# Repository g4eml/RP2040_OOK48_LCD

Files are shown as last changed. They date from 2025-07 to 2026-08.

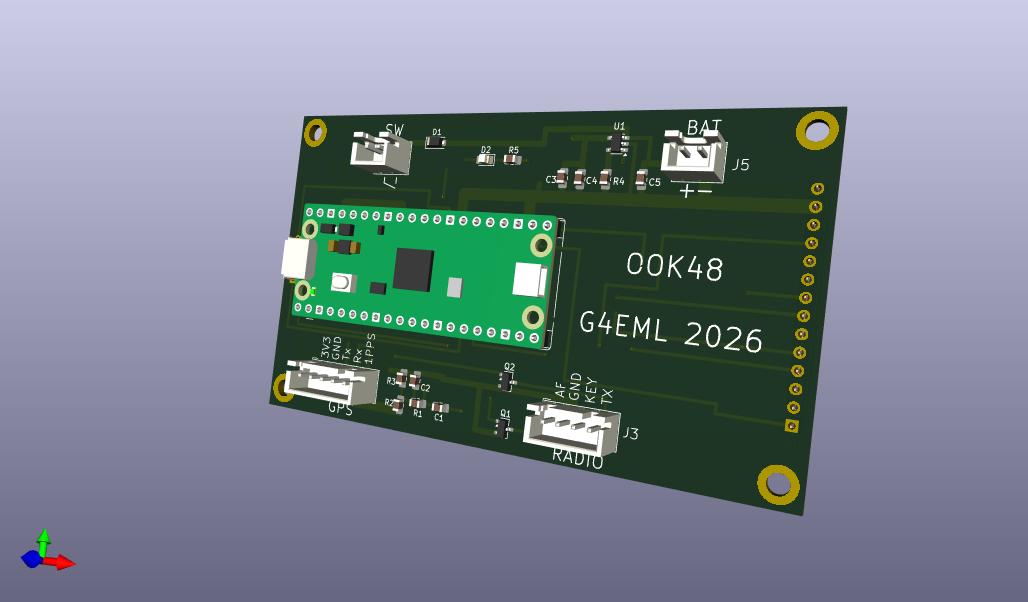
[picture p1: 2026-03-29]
PCB V2/3D View.jpg

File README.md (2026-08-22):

# RP2040 OOK48 LCD

## Description

This Project is an experimental test for a new Synchronous On Off Keying mode for use with weak signal microwave contacts.
The protocol is based on an idea from Andy G4JNT with input from several other UK Microwave Group Members. 
It is described in the document https://github.com/g4eml/RP2040_OOK48_LCD/blob/main/Documents/OOK48%20Protocol.pdf.

## Features

- Uses On/Off keying which is easier to implement than Frequency Shift keying on the higher microwave bands. 

- The data rate is similar to Morse code, so the module can be connected directly to the CW key input of any radio. 

- Real time visual confirmation of the message, character by character. No need to wait 30 seconds to see if the reception has succeeded.

- Uses the GPS 1 Pulse per second signal for accurate character synchronisation.  

- Optional 2 Seconds per character mode which increases the decode sensitiviy slightly. 

- Stand alone Device with LCD touch screen display. 

- No special programming hardware or software required. 

- Programming using the RP2040s built in standard boot loader. 

- 10 Preset Messages are saved to EEPROM for automatic load on power on. 

- Automatic calculation of QTH Lacator. Selectable for 6, 8 or 10 character accuracy. This locator can be inserted in any of the 10 Preset Messages. 

- Recording of messages to SD card for later viewing on a PC.

- USB Drive mode to allow downloading of SD card files to a PC.

- Also now includes encode/decode mode for Morse Code and decode only mode for JT4G and PI4 beacon signals.

## Operation Description

### Display
The display is split into 4 main areas. On the left are the Spectrum display and Waterfall. These are used to tune the reciever to the correct frequency. 

In OOK48 and Morse modes the Spectrum and Waterfall span from 500 Hz to 1100 Hz. Underneath the spectrum display there is an orange band which indicates the correct frequency range for decoding (centred on 800 Hz) . The receiver needs to be tuned such that the received tone falls withing this orange band. 

Received messages will appear at one character per second on the right hand side of the display. 

When Transmitting the Spectrum display is replaced with a RED box and the Text 'TX'. The transmitted message appears on the right hand side in red as it is sent.

In JT4G mode the spectrum and waterfall span 500Hz to 2 KHz. In PI4 mode the span is 500Hz to 1500 Hz.  There are 4 orange bands indicating the 4 data tone frequencies. The receiver needs to be tuned such that the received tones fall withing these orange bands.

### Controls

At the bottom of the screen there are 6 touch buttons.

Clear.   Clears the Message display.

Config. Displays a config page which allows settings to be changed.  

Record Button (Red Circle).  Displayed when a FAT formatted SD card is fitted. Click to start recording of text to the SD card. (GPS must be active). The filename will be based on the current date and time DDMMYY-HHMMSS.txt.

Stop Button (White Square). Displayed when recording is in progress. Click to stop recording. 

App Selecting this shows a new screen with three buttons which are used to select the required mode of operation. OOK48, JT4G Decoder or PI4 Decoder. When selected the system will reboot into the new mode. 

Set Tx.  This shows a menu of the 10 stored messages to be used for transmit. Selecting a messsage allows it to be edited on the next screen. Pressing the Enter Button saves the message.

Tx / Rx   Starts and stops the transmission of the currently selected Message. 

Touching the Waterfall display area of the screen will cycle through a selection of Tone detection ranges indicated by the width of the orange band. 
Available ranges are +-50 Hz, +_ 100Hz and the full width 500-1100 Hz.
Wider ranges require less accurate tuning but have a slightly higher chance of errors with weak signals. 

A 'Factory Reset' can be done by holding your finger on the display while powering on. This will clear the EEPROM to its default values and run the screen calibration routine. 

## USB Drive Mode. 

If an SD card is present there will be an additonal line visible on the Config Page. 'Activate USB Drive Mode" .  Clicking on this button will activate the USB Memory stick emulation mode. You can then connect the HMI module to a PC and the contents of its SD card will appear as a USB drive. This allows the download and deletion of the saved text files without removing the SD card. 

This mode can pnly be exited by powering off the module. 

## Config page settings

- Set Locator Length.  Allows selection of 6, 8 or 10 digit locators.

- Character Period. Selects the normal 1S per character or the optional 2 Seconds per character. Both ends of the link need to have the same settings. 

- GPS Baud Rate. Selects 9600 Baud for the older GPS modules or 38400 for more recent modules.

- GPS Test Mode. If selected the right hand side of the main scree will show the status of the GPS 1PPS signal and NMEA messages, these can be used to confirm the correct operation of the GPS module.
   
- Decode Mode. Selects Normal or Alternate mode. Normal mode is tolerant of frequency drift and chirping. Alternate mode needs a very stable drift free tone but is slightly more sensitive.

- Tx Timing Advance. Allows a fixed delay to be added to compensate for signal processing delays in the Tx chain. (such as DSP audio processing)

- Rx Timing Retard. Allows a fixed delay to be added to compensate for any signal processing delays in the Rx chain. (such as noise reduction)
 
- Default Morse WPM. This is the Morse code speed set at power on. This speed can be adjusted during Morse Reception using the two buttons on the Text Display. 

- Activate USB Drive Mode.  Allows the module to be connected to a PC where it will appear as a USB drive allowing the contents of the SD card to be read or deleted. The module must be powered off to exit this mode. 

- Exit. Return to the previous screen.

- Version Number. 

- Voltage Display. This shows the current battery voltage.  This reading may need calibrating for each module. Measure the true battery voltage with a multimeter. Touch the Displayed voltage and enter the measured value. Exit the calibration screen to save the new calibration value. 

## Hardware Requirements

This code was originally designed to work with the Elecrow CrowPanel Pico-3.5 inch 480x320 TFT LCD HMI Module. https://www.aliexpress.com/item/1005007250778536.html 

hmi

Note:- similar HMI Panels are available using the ESP32 processor chip. Make sure that you are purchasing the RP2040 version. 

However the correct module now appears to be difficult to obtain. A new interface board has been designed to allow a Raspberry Pi Pico to be fitted to a more easily available 3.5" TFT touch panel.



3D View

The LCD screen, controller chip and Touch Screen controller appear to be exactly the same as the original module.
 
If you are searching for these online the critical points are that it needs to be a 3.5" display  320 x 480 resolution with an ILI9488 controller and touch screen. 
There are lots of similar displays out there but the correct ones are usually Red and have 14 connections at one end of the board and 4 connections at the other. Be careful as these are also available without the touch screen. 
Full schematic and PCB designs are in the PCB V2 folder. 
Note that these alternative displays come in at least two different versions.The functionality is the same but the 3D printed enclosure has to be slightly different. The displays can be identified by the position of the flex cable to the touch screen. On the 'Type A' display the flex cable is nearest to the 14 pin connector. On the 'Type B' display the flex cable is nearest to the 4 pin connector. The picture above shows the 'Type A' display.

A GPS module is also essential and must have a 1 Pulse per second output. This pulse is used to synchronise the start of each character. 

gps

## Connecting

### Elecrow module

The receiver is connected to the HMI module via a simple level shifting interface. Details are shown in this document [Connections](Documents/Schematic.pdf)

The  GPS module can be connected the Connector on the top of the module as per the schematic. Alternatively it can be connected to the UART1 connector on the lower edge of the MHI Module. However the 1PPS signal will still need to be connected to the top connector. 

The power is provided by the USB-C connector marked 'USB' on the end of the HMI module, or optionally by a 3.7V lithium cell connected to the BAT connector. 

### New PCB

All of the interfacing components are included on the new PCB. Connect the radio and GPS modules to the marked connectors. A Single Cell Lithium battery can be connected to the BAT connector and an ON/OFF switch to the SW connector. 

## Programming or updating the HMI Module (quick method) 

1. Locate the latest compiled firmware file 'RP2040_OOK48_LCD.uf2' which will be found here https://github.com/g4eml/RP2040_OOK48_LCD/releases and save it to your desktop. 

2. Connect the Module to your PC using the USB-C port. 

3. If using the Elecraft module hold down the BOOT button on the back of the HMI module and briefly press the Reset button. If using the New PCB remove the power and hold down the BOOT button on the Pico while re-applying the power. The RP2040 should appear as a USB disk drive on your PC.

3. Copy the .uf2 file onto the USB drive. The RP2040 will recognise the file and immediately update its firmware and reboot.

## Building your own version of the firmware (longer method and not normally required unless you need to make changes)

The RP2040 is programmed using the Arduino IDE with the Earl F. Philhower, III  RP2040 core. 

#### Installing the Arduino IDE

1. Download and Install the Arduino IDE 2.3.0 from here https://www.arduino.cc/en/software

2. Open the Arduino IDE and go to File/Preferences.

3. in the dialog enter the following URL in the 'Additional Boards Manager URLs' field: https://github.com/earlephilhower/arduino-pico/releases/download/global/package_rp2040_index.json

4. Hit OK to close the Dialog.

5. Go to Tools->Board->Board Manager in the IDE.

6. Type “RP2040” in the search box.

7. Locate the entry for 'Raspberry Pi Pico/RP2040 by Earle F. Philhower, III' and click 'Install'

### Installing the required libraries

1. From the Arduino IDE select (Tools > Manage Libraries)
2. Search for 'arduinoFFT' Scroll down to find the arduinoFFT library by Enrique Condes.
3. Click Install
4. Now search for 'TFT_eSPI' and find the TFT graphics library by Bodmer.
5. Click Install
6. Now search for 'SdFat - Adafruit Fork" and find the library by Bill Greiman.
7. Click Install

#### Downloading the Software.

1. Download the latest released source code .zip file from https://github.com/g4eml/RP2040_OOK48_LCD/releases

2. Save it to a convenient location and then unzip it. 

The TFT_eSPI Library is unusual in that it needs to be configured to the TFT display in use by modifying library files. 
The required modified versions of the files are located in the 'LCD-eSPI Settings' folder of this repository. 
Copy the files 'Setup_Elecraft_HMI.h' and 'User_Setup_Select.h' from  the downloaded 'LCD-eSPI Settings' folder to your Arduino libraries directory.
This will normaly be found at 'Documents/Arduino/libraries/TFT_eSPI'

#### Programming the RP2040

1. Open the Arduino IDE and click File/Open

2. Navigate to the File RP2404Synth/RP2040_OOK48_LCD.ino (downloaded in the previous step) and click Open.

3. Select Tools and make the following settings.

   Board: "Raspberry Pi Pico"

   Port: "UF2 Board"
   
   Debug Level: "None"

   Debug Port: "Disabled"

   C++ Exceptions: "Disabled"

   Flash Size: "2Mb (no FS)"

   CPU Speed: "200MHz"

   IP/Bluetooth Stack: "IPV4 Only"

   Optimise: "Small (-Os)(standard)"

   RTTI: "Disabled"

   Stack Protection: "Disabled"

   Upload Method: "Default (UF2)"

   USB Stack: "Adafruit TinyUSB"  

5. Connect the Module to the USB port, hold down the BOOT button while powering on. 

6. Click Sketch/Upload.

The Sketch should compile and upload automatically to the Pico. If the upload fails you may need to disconnect the module and then hold down the BOOT button while reconnecting. 

## Connections

The receiver audio is connected using a simple CR network to GPIO Pins GND, 3V3 and 28 on the top edge of the HMI Module. 
Details of this interface are in this file.  Interface

IO Pin 6 is connected to to gate of an N channel Mosfet. The drain of this Mosfet is connected to the PTT input of the radio.
IO Pin 7 is connected to to gate of an N channel Mosfet. The drain of this Mosfet is connected to the Key input of the radio.   

The firmware requires the connection of a GPS module. This is used to accurately set the time and to generate the 1 Pulse per second signal used to synchromise the satrt of each character. Any GPS module with a 3V3 output and a 1PPS output can be used. It needs to output NMEA data at 9600 Baud or 38400 Baud. One of the G10A-F30 modules was used for development.
GPS data to the HMI module is connected to IO pin 5.
GPS data from the HMI module is connected to IO pin 4.
1 PPS pulse from the GPS module is conneced to IO pin 3.

## 3D Printed Enclosure

Files for 3D printable enclosures for the each of the display variants are included in the Enclosure directory. 

Additional parts required.
- 3 Phono Sockets for Audio Input, Key Output and PTT Output
- PAM8403 amplifier module with volume control. Wired in parallel with input audio to allow monitoring of the signal 
- 28mm Speaker 
- 18650 Lithium Cell. (can be switched with the audio amp voulme control on/off switch)

Pam2303
Speaker

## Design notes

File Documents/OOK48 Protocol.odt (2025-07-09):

Provisional GNSS synchronised on off keying protocol ‘OOK48’

Transmit

Messages are sent one character at a time at a rate of one character per second.

The start of each 1 second timeslot is defined by the GNSS derived 1PPS signal.

Each 1 Second timeslot is divided into 9 equal periods of 1/9th second each.

The first 8 periods are used to send the 4 from 8 coded version of the character.

The 8 bits of the 4 from 8 value are sent MSB first. A one is sent as Key Down. A Zero is sent as Key Up.

The 9th period is sent with Key Up and does not form part of the character. It is to allow the receiver time to decode and display the character. The 9th period can also be shortened or lengthened as needed by the receiver to maintain sync with the 1PPS signal.

Ascii characters from 32 (space) to 95 (_) are mapped to the 70 available 4 from 8 values.

Lower case letters are mapped to their upper case equivalent.

A CR character is used to define the end of the message.

The last 5 of the 4 from 8 values are currently unused but could be used for additional control characters if needed.

Messages are repeated for as long as the transmission lasts. There is no gap between repeats.

Message length is not defined but each message ends with a CR character. This would allow a short message like a report to be repeated rapidly many times. Typical longer lengths would be about 15 to 30 characters taking 15 or 30 seconds to send.

Receive

My experimental system does the following...

Reception of each character starts on the GNS derived 1PPS signal. The ADC DMA sampling is started by this signal.

1024 ADC Samples are repeatedly taken using DMA at a sample rate of 9216 samples per second. Each capture therefore takes 1/9th of a second or one bit period.

As each capture becomes available the following is done

Apply Hanning window.

FFT transform.

Calculate the 512 Bin Magnitudes. Each bin is 9 Hz wide.

Use some of these bins to display the Spectrum and Waterfall.

Save all the FFT bins that fall within the tone search window for this capture to a large array.

Tone centre frequency is 800Hz and the available search widths are +_50 Hz, +-100Hz, +_250Hz, +-500Hz and the full 300 -2200 Hz Spectrum. Wider search widths require less precise tuning but increase the risk if the tone being incorrectly detected.

After 8 captures attempt to decode the received character.

There are two slightly different decode modes, selectable from the configuration page. Normal decode gives slightly better sensitivity but relies on the received tone frequency being stable and remaining in the same FFT bin for the whole character. Alternate decode allows a less stable received tone to drift between bins during the character. This can be useful for the higher microwave bands where stability can be difficult to achieve.

Normal Decode.

Search the saved FFT bins and find the bin that contains the tone.

Currently this is done by looking for the bin with the largest Max to Min range. This seems to work however there may be better ways to do this. Using the same bin for all 8 timeslots save the 8 magnitudes for the next step.

Alt Decode.

Search the saved FFT bins and find the bin with the highest magnitude. Repeat this search for each of the 8 of the timeslots. Save these 8 magnitudes for the next step.

Normal and Alt Decode.

Examine the 8 captured magnitudes and find the highest 4 magnitudes. Set these bits to one and set the remaining bits to 0. This will always form a valid 4 from 8 value although this value may be in error. Look up the ASCII character and display this.

An additional experimental 2 seconds per character mode is also being tried. In this mode the transmitter repeats each character with the first character being sent at the start of every Even GPS second.

The receiver now sums the two received characters before decoding. This give a slight improvement in low signal sensitivity.

Timing Adjustment.

To allow for modern radios that use DSP processing the Tx start of character can be advanced from the 1PPS signal to compensate for any delay between Key down and the start of the RF output.

Likewise the ADC start time during Rx can be retarded to allow for any audio processing delays.

These settings are made using the config menu.

These settings may need to be adjusted to ensure the ‘Over the air’ signal is exactly synchronised to the GPS 1PPS signal.

4 from 8 value to ASCII mapping is shown in the next table.

Colin Durbridge G4EML 05/06/25

4 From 8 | Ascii | Char | 4 From 8 | Ascii | Char
15 | 13 | CR | 135 | 66 | B
23 | 32 | Space | 139 | 67 | C
27 | 33 | ! | 141 | 68 | D
29 | 34 | “ | 142 | 69 | E
30 | 35 | # | 147 | 70 | F
39 | 36 | $ | 149 | 71 | G
43 | 37 | % | 150 | 72 | H
45 | 38 | & | 153 | 73 | I
46 | 39 | ‘ | 154 | 74 | J
51 | 40 | ( | 156 | 75 | K
53 | 41 | ) | 163 | 76 | L
54 | 42 | * | 165 | 77 | M
57 | 43 | + | 166 | 78 | N
58 | 44 | , | 169 | 79 | O
60 | 45 | - | 170 | 80 | P
71 | 46 | . | 172 | 81 | Q
75 | 47 | / | 177 | 82 | R
77 | 48 | 0 | 178 | 83 | S
78 | 49 | 1 | 180 | 84 | T
83 | 50 | 2 | 184 | 85 | U
85 | 51 | 3 | 195 | 86 | V
86 | 52 | 4 | 197 | 87 | W
89 | 53 | 5 | 198 | 88 | X
90 | 54 | 6 | 201 | 89 | Y
92 | 55 | 7 | 202 | 90 | Z
99 | 56 | 8 | 204 | 91 | [
101 | 57 | 9 | 209 | 92 | \
102 | 58 | : | 210 | 93 | ]
105 | 59 | ; | 212 | 94 | ^
106 | 60 | < | 216 | 95 | _
108 | 61 | = | 225 | Spare | ~
113 | 62 | > | 226 | Spare | ~
114 | 63 | ? | 228 | Spare | ~
116 | 64 | @ | 232 | Spare | ~
120 | 65 | A | 240 | Spare | ~

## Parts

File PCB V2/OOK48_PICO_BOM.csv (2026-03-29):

Reference | Qty | Value
A1 | 1 | RaspberryPi_Pico
C1,C3 | 2 | 100nF
C2 | 1 | 10uF
C4,C5 | 2 | 22uF
D1 | 1 | BAT42W
D2 | 1 | 0805 LED RED
J1 | 1 | Conn_01x14_SIL Socket
J2 | 1 | Conn_01x04_SIL Socket
J3 | 1 | JST_XH_B4B-XH-A
J4 | 1 | JST_XH_B5B-XH-A
J5,J6 | 2 | :JST_XH_B2B-XH-A
Q1,Q2 | 2 | DMN3404L
R1 | 1 | 10K
R2,R3 | 2 | 47K
R4 | 1 | 2K
R5 | 1 | 4K7
U1 | 1 | LTC4054ES5-4.2

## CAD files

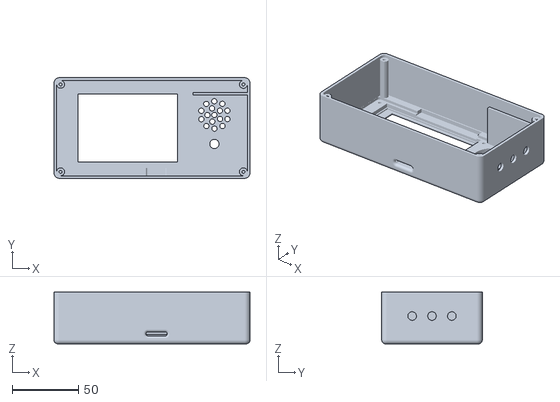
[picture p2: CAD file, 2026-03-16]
Enclosure/Elecrow Module/OOK48 Box.stl
148.0 x 76.0 x 39.1

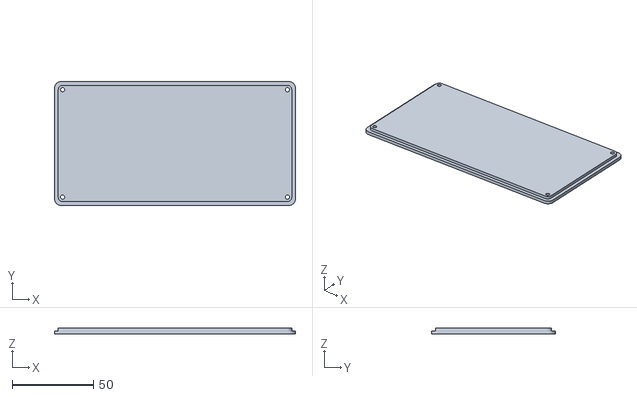
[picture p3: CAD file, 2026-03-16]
Enclosure/New PCB Type A Display/OOK48 Box Lid.stl
148.0 x 76.0 x 3.80

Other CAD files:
Enclosure/New PCB Type A Display/OOK48 Box A.stl
Enclosure/New PCB Type B Display/OOK48 Box B.stl

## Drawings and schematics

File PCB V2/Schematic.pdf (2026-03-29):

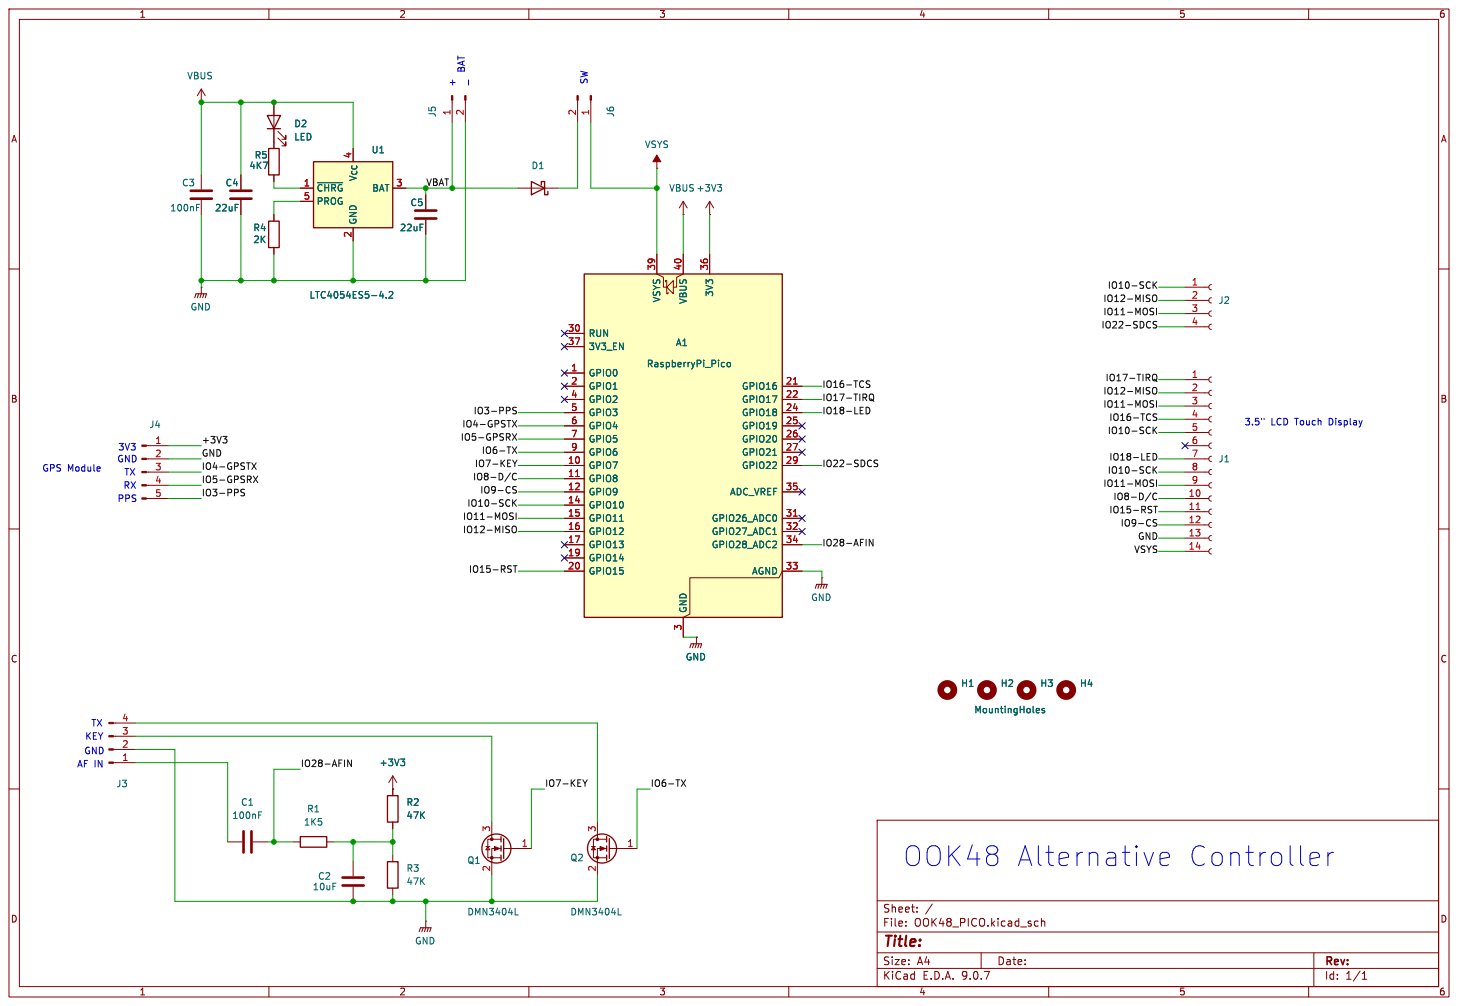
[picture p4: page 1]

3.5" LCD Touch Display GPS Module GND

Id: 1/1 Title: File: OOK48_PICO.kicad_sch Sheet: / 1

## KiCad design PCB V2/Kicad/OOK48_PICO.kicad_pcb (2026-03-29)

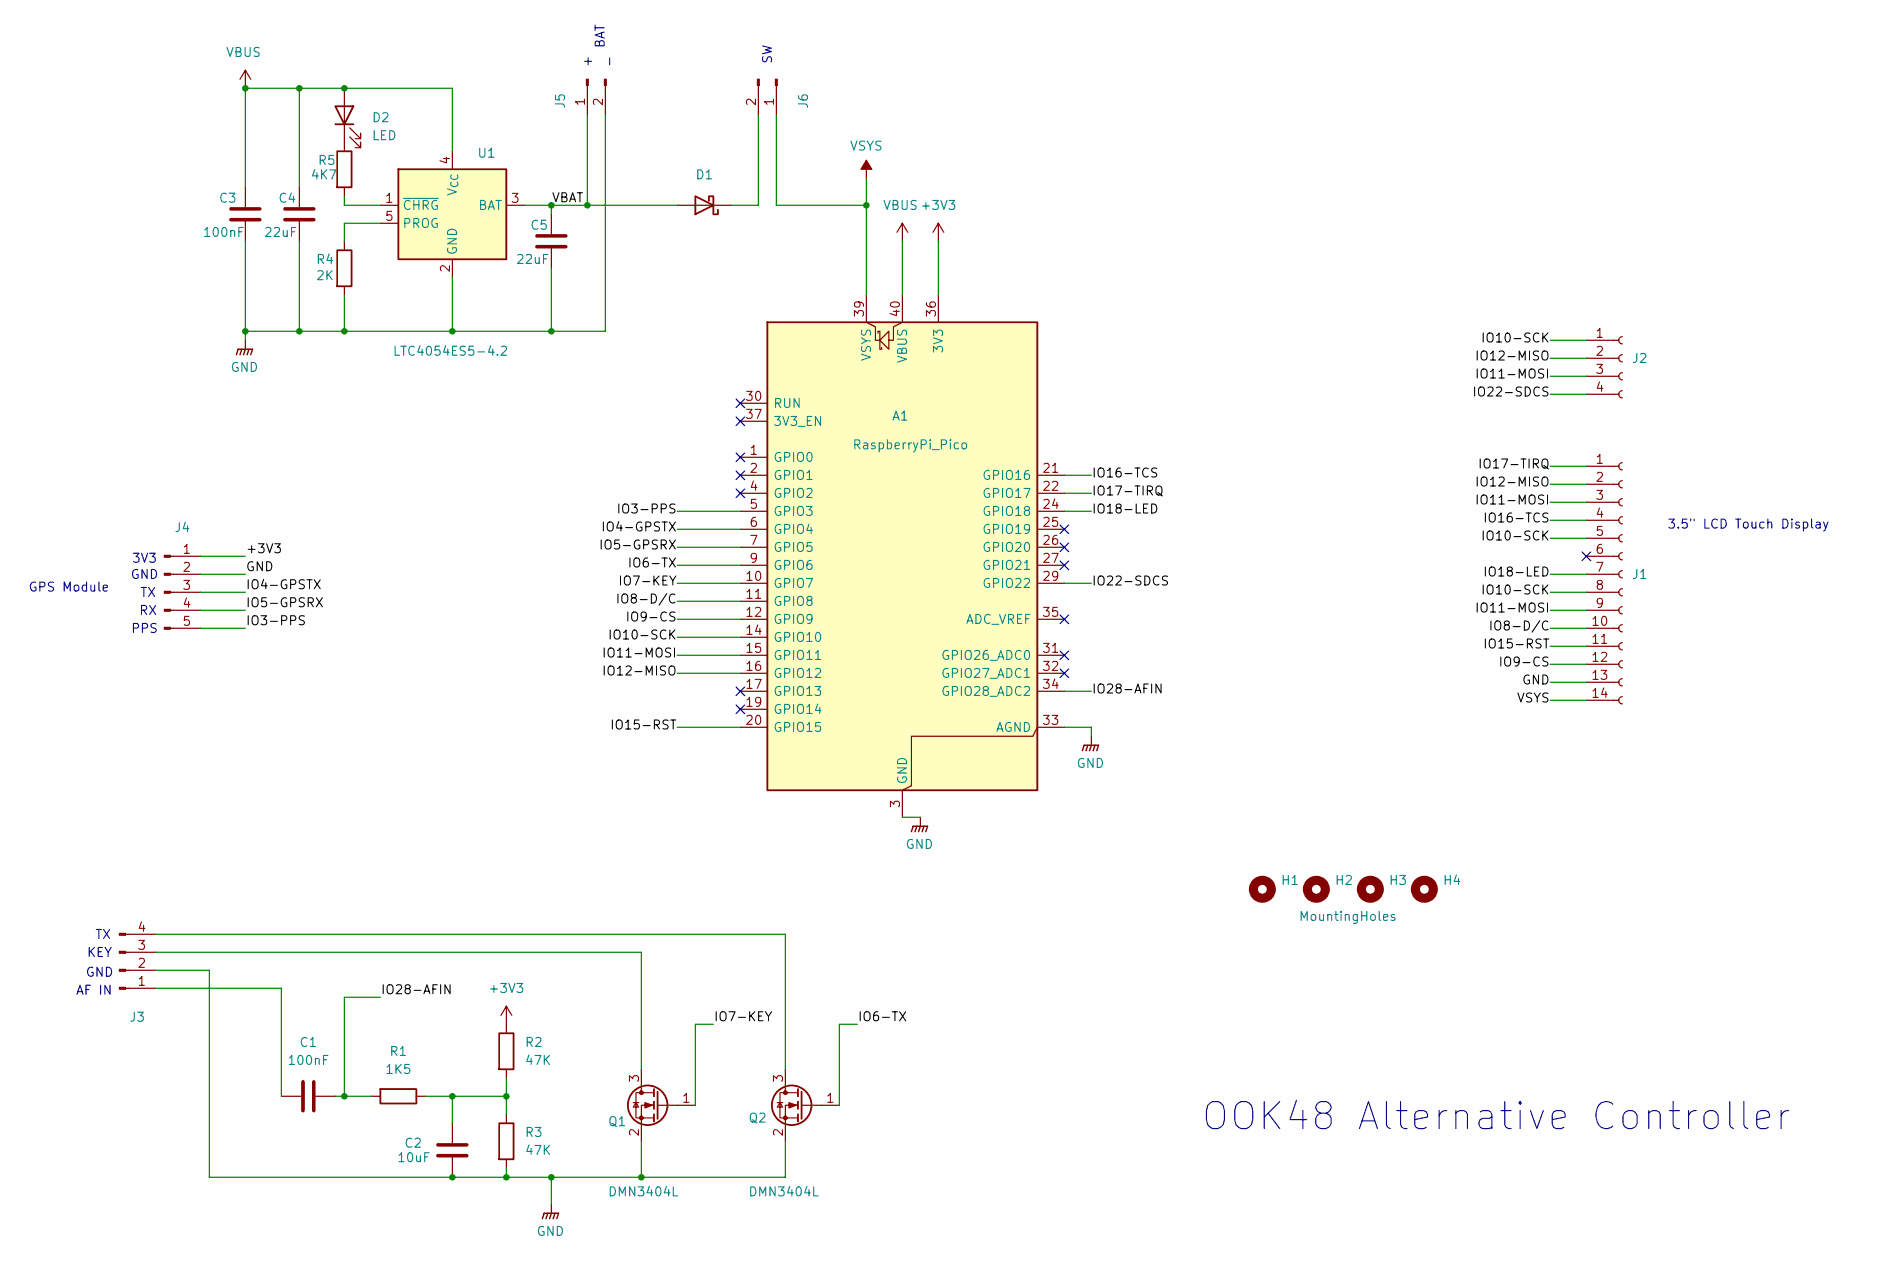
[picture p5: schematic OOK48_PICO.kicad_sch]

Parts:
A1: RaspberryPi_Pico; RaspberryPi_Pico_Common_THT
C1, C3: 100nF; C_0805_2012Metric_Pad1.18x1.45mm_HandSolder
C2: 10uF; C_0805_2012Metric_Pad1.18x1.45mm_HandSolder
C4, C5: 22uF; C_0805_2012Metric_Pad1.18x1.45mm_HandSolder
D1: D_Schottky; D_SOD-123F
D2: LED; LED_0805_2012Metric_Pad1.15x1.40mm_HandSolder
H1, H2, H3: MountingHole; MountingHole_3.2mm_M3_ISO14580_Pad
H4: MountingHoles; MountingHole_3.2mm_M3_ISO14580_Pad
J1: Conn_01x14_Socket; PinSocket_1x14_P2.54mm_Vertical
J2: Conn_01x04_Socket; PinSocket_1x04_P2.54mm_Vertical
J3: Conn_01x04_Pin; JST_XH_B4B-XH-A_1x04_P2.50mm_Vertical
J4: Conn_01x05_Pin; JST_XH_B5B-XH-A_1x05_P2.50mm_Vertical
J5, J6: Conn_01x02_Pin; JST_XH_B2B-XH-A_1x02_P2.50mm_Vertical
Q1, Q2: DMN3404L; SOT-23
R1: 1K5; C_0805_2012Metric_Pad1.18x1.45mm_HandSolder
R2, R3: 47K; C_0805_2012Metric_Pad1.18x1.45mm_HandSolder
R4: 2K; C_0805_2012Metric_Pad1.18x1.45mm_HandSolder
R5: 4K7; C_0805_2012Metric_Pad1.18x1.45mm_HandSolder
U1: LTC4054ES5-4.2; TSOT-23-5

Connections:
+3V3: A1.36 (3V3), J4.1, R2.1
/IO3-PPS: A1.5 (GPIO3), J4.5
/IO4-GPSTX: A1.6 (GPIO4), J4.3
/IO5-GPSRX: A1.7 (GPIO5), J4.4
/IO6-TX: A1.9 (GPIO6), Q2.1 (G)
/IO7-KEY: A1.10 (GPIO7), Q1.1 (G)
/IO8-D/C: A1.11 (GPIO8), J1.10
/IO9-CS: A1.12 (GPIO9), J1.12
/IO10-SCK: A1.14 (GPIO10), J1.5, J1.8, J2.1
/IO11-MOSI: A1.15 (GPIO11), J1.3, J1.9, J2.3
/IO12-MISO: A1.16 (GPIO12), J1.2, J2.2
/IO15-RST: A1.20 (GPIO15), J1.11
/IO16-TCS: A1.21 (GPIO16), J1.4
/IO17-TIRQ: A1.22 (GPIO17), J1.1
/IO18-LED: A1.24 (GPIO18), J1.7
/IO22-SDCS: A1.29 (GPIO22), J2.4
/IO28-AFIN: A1.34 (GPIO28_ADC2), C1.2, R1.2
/VBAT: C5.2, D1.2 (A), J5.1, U1.3 (BAT)
GND: A1.3 (GND), A1.8 (GND), A1.13 (GND), A1.18 (GND), A1.23 (GND), A1.28 (GND), A1.33 (AGND), A1.38 (GND), C2.1, C3.1, C4.1, C5.1, J1.13, J3.2, J4.2, J5.2, Q1.2 (S), Q2.2 (S), R3.2, R4.2, U1.2 (GND)
unnamed: C2.2, R1.1, R2.2, R3.1
unnamed: D1.1 (K), J6.2
unnamed: D2.1 (K), R5.1
unnamed: C1.1, J3.1
unnamed: J3.3, Q1.3 (D)
unnamed: J3.4, Q2.3 (D)
unnamed: R4.1, U1.5 (PROG)
unnamed: R5.2, U1.1 (~CHRG)
VBUS: A1.40 (VBUS), C3.2, C4.2, D2.2 (A), U1.4 (V_{CC})
VSYS: A1.39 (VSYS), J1.14, J6.1

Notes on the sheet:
KEY
GND
OOK48 Alternative Controller
GPS Module
BAT
PPS
3V3
3.5" LCD Touch Display
AF IN

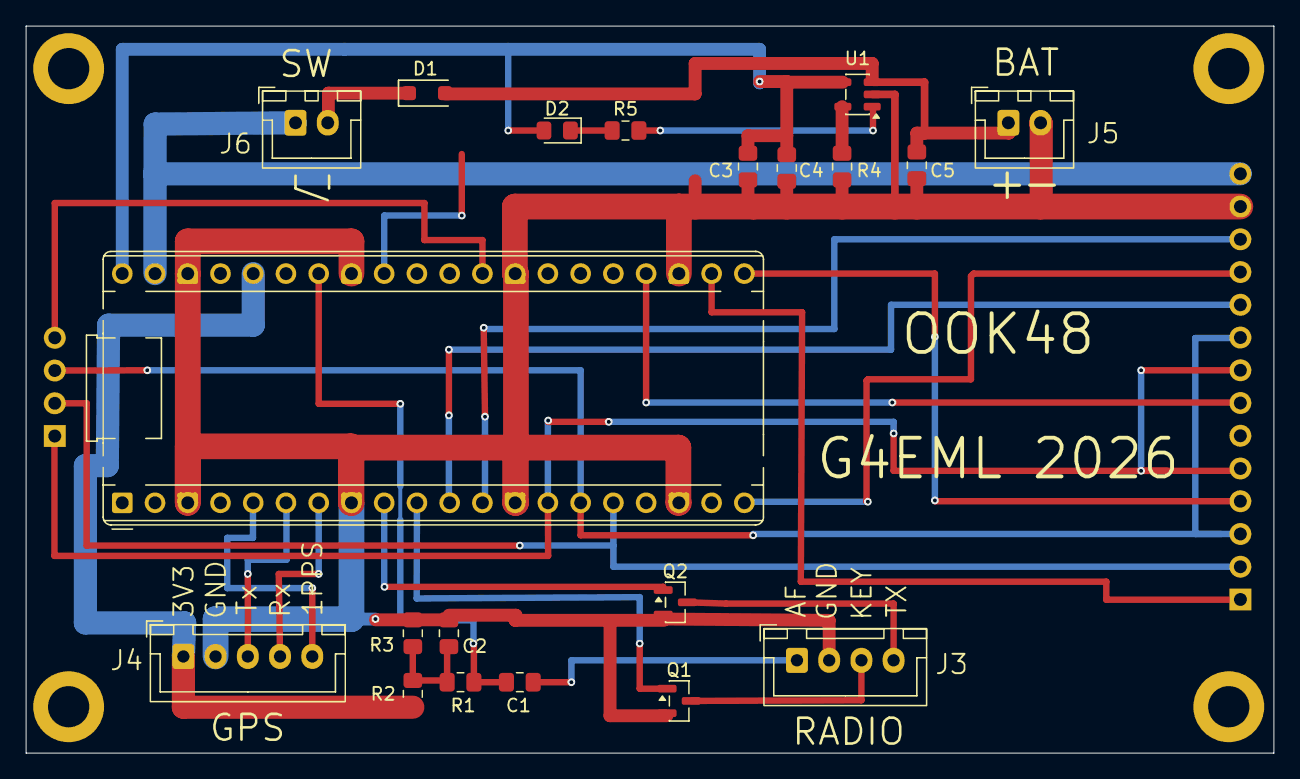
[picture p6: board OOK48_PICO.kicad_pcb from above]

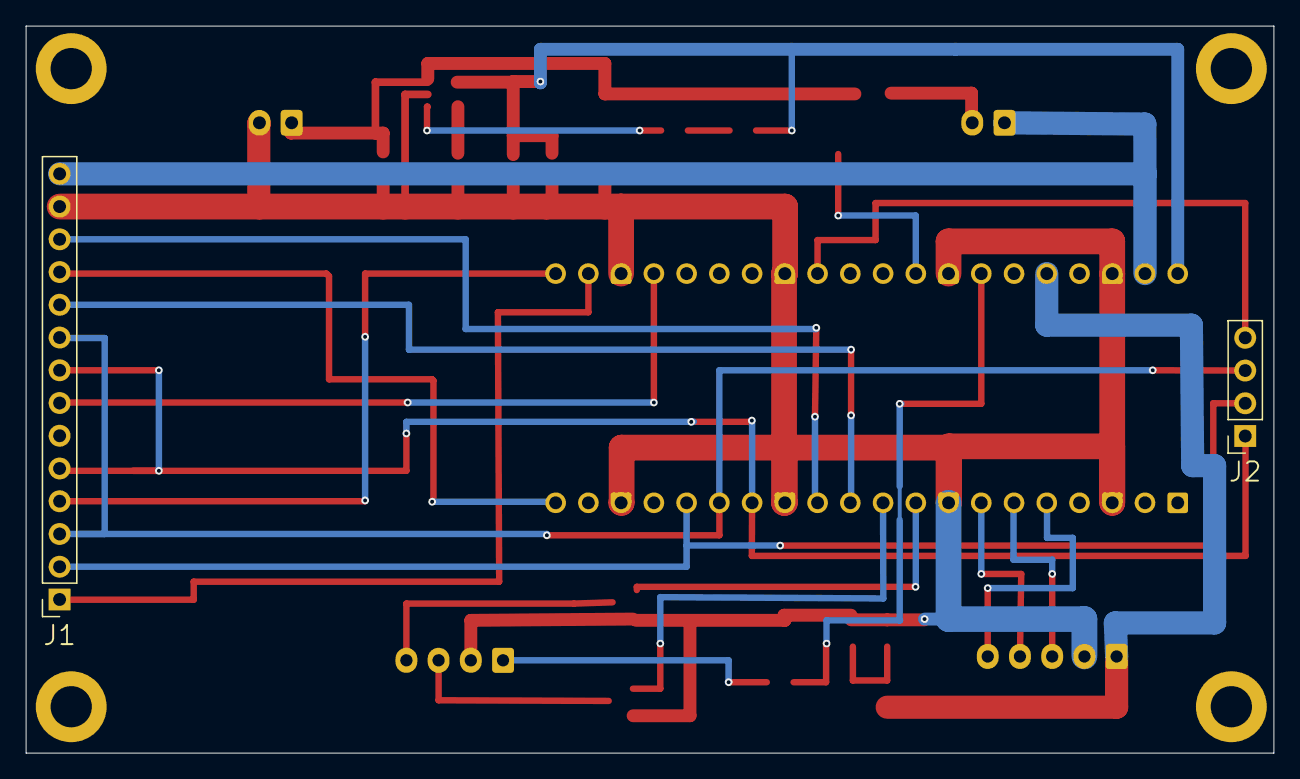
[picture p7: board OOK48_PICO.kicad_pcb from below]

Board: 2 copper layers, 96.8 x 56.4 mm, 26 parts (2 on the bottom side), 29 nets.

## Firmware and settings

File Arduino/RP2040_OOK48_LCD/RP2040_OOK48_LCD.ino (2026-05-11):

// OOK48 Encoder and Decoder LCD version
// Plus Beacon Decoder
// Plus Morse Encoder and Decoder
// Colin Durbridge G4EML 2026


#include <hardware/dma.h>
#include <hardware/adc.h>
#include "hardware/irq.h"
#include "arduinoFFT.h"
#include <EEPROM.h>
#include <TFT_eSPI.h>                 // Hardware-specific library. Must be pre-configured for this display and touchscreen
#include "DEFINES.h"                  //include the defines for this project
#include "globals.h"                  //global variables
#include "float.h"
#include <SPI.h>
#include "SdFat_Adafruit_Fork.h"
#include "Adafruit_TinyUSB.h"
#include "morse_tx.h"

SdFat sd;

SdFile sdfile;

Adafruit_USBD_MSC usb_msc;                // USB Mass Storage object

#define SD_CONFIG SdSpiConfig(SDCS, SHARED_SPI,SD_SCK_MHZ(12), &SPI1)

TFT_eSPI tft = TFT_eSPI();            // Invoke custom library
 
ArduinoFFT<float> FFT = ArduinoFFT<float>(sample, sampleI, NUMBEROFSAMPLES, SAMPLERATE);         //Declare FFT function

struct repeating_timer TxIntervalTimer;                   //repeating timer for Tx bit interval

struct repeating_timer PPSIntervalTimer;                  // and another for the 1PPS signal delay

static MorseTx morseTx;

volatile bool core0Ready = false;
volatile bool core1Ready = false;

//Run once on power up. Core 0 does the time critical work. Core 1 handles the GUI.  
void setup() 
{
    EEPROM.begin(1024);
    loadSettings(0);
    pinMode(PPSINPUT,INPUT);
    pinMode(KEYPIN,OUTPUT);
    digitalWrite(KEYPIN,0);
    pinMode(TXPIN,OUTPUT);
    digitalWrite(TXPIN,0);
    core0Ready = true;                    //signal this core is ready. 
    while(!core1Ready);                   //wait for core 1 to be ready. 
    if (isOokLikeApp())
     {
       mode = RX;  
       RxInit();
       TxMessNo = 0;
       TxInit();
     }
     else           //Beacon Decoder
     {
      if(settings.app == BEACONPI4)
      {
       beaconMode = PI4;
       PI4Init();
      }
      else 
      {
       beaconMode = JT4;
       JT4Init();
      }
     }
      attachInterrupt(PPSINPUT,ppsISR,RISING);
}

//Interrupt called every symbol time to update the Key output. 
bool TxIntervalInterrupt(struct repeating_timer *t)
{
    if (morseTx.isActive())
    {
        morseTx.tick(mode == TX, Key);
        return true;
    }

    TxSymbol();
    return true;
}

//Interrupt called when the 1PPS delay has expired. 
bool PPSIntervalInterrupt(struct repeating_timer *t)
{
  doPPS();
  return false;                   //dont retrigger this timer
}

//1PPS Interrupt 
void ppsISR(void)
{
  PPSActive = 3;
 if(settings.app == OOK48)            //we are only interested in the 1PPS interrupt for OOK48 mode
 {
  if(mode == RX)
  {
   if(settings.rxRetard == 0)          // no delay, call the 1PPS routine immediately
   {
    doPPS();
   }
   else                                 // call the 1PPS routine after a delay 
   {
      add_repeating_timer_ms(settings.rxRetard,PPSIntervalInterrupt,NULL,&PPSIntervalTimer);    //start a delayed callback
   }
  }

  else                //Tx
  {
   if(settings.txAdvance == 0)           // no delay, call the 1PPS routine immediately
   {
    doPPS();
   }
   else                                 // call the 1PPS routine after a delay 
   {
      add_repeating_timer_ms(1000 - settings.txAdvance,PPSIntervalInterrupt,NULL,&PPSIntervalTimer);    //start a delayed callback
   }
  }
 }
}


// Indirect interrupt routine for 1 Pulse per second input Delayed by retard or advance settings. 
void doPPS(void)
{
    if (mode == RX)
    {
        dma_stop();
        dma_handler();
        dmaReady = 0;
        if ((halfRate == false) || (halfRate & (gpsSec & 0x01)))
            cachePoint = 0;
        else
            cachePoint = 8;
    }
    else
    { 
      cancel_repeating_timer(&TxIntervalTimer);
      add_repeating_timer_us(-TXINTERVAL, TxIntervalInterrupt, NULL, &TxIntervalTimer);
      TxSymbol();
    }

}

//core 1 handles the GUI
void setup1()
{
  Serial2.setRX(GPSRXPin);              //Configure the GPIO pins for the GPS module
  Serial2.setTX(GPSTXPin);
  
  while (!core0Ready) delay(1);         //wait for Core 0 to initialise
  
  Serial2.begin(settings.gpsBaud);    

  SPI1.setRX(SDO);
  SPI1.setTX(SDI);
  SPI1.setSCK(SDCLK);

  sdpresent = sd.begin(SD_CONFIG);

  if(sdpresent)
    {
       SdFile::dateTimeCallback(dateTime);           //set a callback function to set the files attributes. 
    }
  core1Ready = true;                                //allow core 0 to continue.

  gpsPointer = 0;
  waterRow = 0;
  initGUI();
  homeScreen();
  textClear();
  switch(settings.app)
   {
    case OOK48:
    textPrintLine("OOK48 Selected");
    break;
    case BEACONJT4:
    textPrintLine("JT4G Selected");
    break;
    case BEACONPI4:
    textPrintLine("PI4 Selected");
    break;
    case MORSE: 
    textPrintLine("Morse Selected");
    break;   
   }
   textPrintLine("");
}


//Main Loop Core 0. Runs forever. Does most of the work.
void loop() 
{
    if (isOokLikeApp())
    {
        if (mode == RX)
            RxTick();
        else
        {
            TxTick();
            if (morseTx.consumeCompleteRequest())
            {
                mode = RX;
                digitalWrite(KEYPIN, 0);
                digitalWrite(TXPIN, 0);
                Key = 0;
                cancel_repeating_timer(&TxIntervalTimer);
            }
        }
    }
    else
    {
        beaconTick();
    }
}


//Core 1 handles the GUI. Including synchronising to GPS if available
void loop1()
{
  uint32_t command;
  uint32_t value;
  char m[64];
 
    if((gpsSec != lastSec) | (millis() > lastTimeUpdate + 2000))
    {         
      showTime();                                   //display the time
      if(PPSActive >0) PPSActive--;                 //decrement the PPS active timeout. (rest by the next PPS pulse)
      lastSec = gpsSec;
      lastTimeUpdate = millis();
    }


  if(rp2040.fifo.pop_nb(&command))          //have we got something to process from core 0?
    {
      switch(command & 0xFFFF)
      {
        case GENPLOT:
        generatePlotData();
        break;
        case DRAWSPECTRUM:
        drawSpectrum();
        break;
        case DRAWWATERFALL:
        drawWaterfall();
        break;
        case REDLINE:
        markWaterfall(TFT_RED);
        break;
        case CYANLINE:
        markWaterfall(TFT_CYAN);
        break;
        case MESSAGE:
        textPrintChar(command >> 16,TFT_BLUE);                                 
        break;
        case TMESSAGE:
        textPrintChar(command >> 16,TFT_RED);                               
        break;
        case JTMESSAGE:
        sprintf(m,"%02d:%02d %.0lf :%s",gpsHr,gpsMin, sigNoise,JTmessage);
        textPrintLine(m);                                 
        break;
        case PIMESSAGE:
        sprintf(m,"%02d:%02d %.0lf :%s",gpsHr,gpsMin, sigNoise,PImessage);
        textPrintLine(m);                                  
        break;
        case MORSEMESSAGE:
        textPrintChar(command >> 16,TFT_BLUE);
        break;
        case MORSELOCKED:
        break;
        case MORSELOST:
        break;
      }
    }


  if((screenTouched()) && (noTouch))
    {
      processTouch();
    } 

  if(Serial2.available() > 0)           //data received from GPS module
      {
        while(Serial2.available() >0)
          {
            gpsCh=Serial2.read();
            if(gpsCh > 31) gpsBuffer[gpsPointer++] = gpsCh;
            if((gpsCh == 13) || (gpsPointer > 255))
              {
                gpsBuffer[gpsPointer] = 0;
                processNMEA();
                gpsPointer = 0;
              }
          }

      }
}

bool isOokLikeApp(void)
{
    return (settings.app == OOK48 || settings.app == MORSE);
}

void processNMEA(void)
{
  float gpsTime;
  float gpsDate;

 gpsActive = true;
 if(RMCValid())                                               //is this a valid RMC sentence?
  {
    if(GPSDebug)
     {
     if(PPSActive >0)
      {
        textPrintLine("1 PPS present");
      }
      else
      {
        textPrintLine("1 PPS Not present");
      }
     textPrintLine(gpsBuffer); 
     }
    int p=strcspn(gpsBuffer , ",") +1;                        // find and skip the first comma
    p= p + strcspn(gpsBuffer+p , ",") + 1;                    // find and skip the second comma 
    if(gpsBuffer[p] == 'A')                                   // is the data valid?
      {
       p=strcspn(gpsBuffer , ",") +1;                         // find and skip the first comma again
       gpsTime = strtof(gpsBuffer+p , NULL);                  //copy the time to a floating point number
       gpsSec = int(gpsTime) % 100;
       gpsTime = gpsTime / 100;
       gpsMin = int(gpsTime) % 100; 
       gpsTime = gpsTime / 100;
       gpsHr = int(gpsTime) % 100;  

       p= p + strcspn(gpsBuffer+p , ",") + 1;                  // find and skip the second comma 
       p= p + strcspn(gpsBuffer+p , ",") + 1 ;                 // find and skip the third comma
       latitude = strtof(gpsBuffer+p , NULL);                  // copy the latitude value
       latitude = convertToDecimalDegrees(latitude);           // convert to ddd.ddd
       p = p + strcspn(gpsBuffer+p , ",") + 1;                 // find and skip the fourth comma  
       if(gpsBuffer[p] == 'S')  latitude = 0-latitude;         // adjust southerly Lats to be negative values                
       p = p + strcspn(gpsBuffer+p , ",") + 1;                 // find and skip the fifth comma      
       longitude = strtof(gpsBuffer+p , NULL);                 // copy the lpngitude value 
       longitude = convertToDecimalDegrees(longitude);         // convert to ddd.ddd   
       p = p + strcspn(gpsBuffer+p , ",") + 1;                 // find and skip the sixth comma  
       if(gpsBuffer[p] == 'W')  longitude = 0 - longitude;     // adjust easterly Longs to be negative values 
       p = p + strcspn(gpsBuffer+p , ",") + 1;                 // find and skip the seventh comma 
       p = p + strcspn(gpsBuffer+p , ",") + 1;                 // find and skip the eighth comma 
       p = p + strcspn(gpsBuffer+p , ",") + 1;                 // find and skip the nineth comma 

       gpsDate = strtof(gpsBuffer+p , NULL);                  //copy the time to a floating point number
       gpsYear = int(gpsDate) % 100;
       gpsDate = gpsDate / 100;
       gpsMonth = int(gpsDate) % 100; 
       gpsDate = gpsDate / 100;
       gpsDay = int(gpsDate) % 100;

       convertToMaid();     
      }
    else
     {
       gpsSec = -1;                                            //GPS time not valid
       gpsMin = -1;
       gpsHr = -1;
       latitude = 0;
       longitude = 0;
       strcpy(qthLocator,"----------");
       qthLocator[settings.locatorLength] = '\0'; // Shorten Locator string
     }
  }


}

bool RMCValid(void)
{
  if((gpsBuffer[3] == 'R') && (gpsBuffer[4] == 'M') && (gpsBuffer[5] == 'C'))
   {
    return checksum(gpsBuffer);
   }
   else 
   {
    return false;
   }
}

// Converts dddmm.mmm format to decimal degrees (ddd.ddd)
float convertToDecimalDegrees(float dddmm_mmm) 
{
    int degrees = (int)(dddmm_mmm / 100);                 // Extract the degrees part
    float minutes = dddmm_mmm - (degrees * 100);         // Extract the minutes part
    float decimalDegrees = degrees + (minutes / 60.0);   // Convert minutes to degrees
    return decimalDegrees;
}

void convertToMaid(void)
{
      // convert longitude to Maidenhead

    float d = 180.0 + longitude;
    d = 0.5 * d;
    int ii = (int)(0.1 * d);
    qthLocator[0] = char(ii + 65);
    float rj = d - 10.0 * (float)ii;
    int j = (int)rj;
    qthLocator[2] = char(j + 48);
    float fpd = rj - (float)j;
    float rk = 24.0 * fpd;
    int k = (int)rk;
    qthLocator[4] = char(k + 65);
    fpd = rk - (float)(k);
    float rl = 10.0 * fpd;
    int l = (int)(rl);
    qthLocator[6] = char(l + 48);
    fpd = rl - (float)(l);
    float rm = 24.0 * fpd;
    int mm = (int)(rm);
    qthLocator[8] = char(mm + 65);
    //  convert latitude to Maidenhead
    d = 90.0 + latitude;
    ii = (int)(0.1 * d);
    qthLocator[1] = char(ii + 65);
    rj = d - 10. * (float)ii;
    j = (int)rj;
    qthLocator[3] = char(j + 48);
    fpd = rj - (float)j;
    rk = 24.0 * fpd;
    k = (int)rk;
    qthLocator[5] = char(k + 65);
    fpd = rk - (float)(k);
    rl = 10.0 * fpd;
    l = int(rl);
    qthLocator[7] = char(l + 48);
    fpd = rl - (float)(l);
    rm = 24.0 * fpd;
    mm = (int)(rm);
    qthLocator[9] = char(mm + 65);
    qthLocator[settings.locatorLength] = '\0'; // Shorten Locator string
}

void loadSettings(bool reset)
{
  bool ss = false;
  EEPROM.get(0,settings);             //read the settings structure

  if((settings.baudMagic != 42) || (reset))
   {
     if(autoBaud(9600))
      {
        settings.gpsBaud = 9600;
        settings.baudMagic = 42;
        ss=true;
      }
    else 
      {
        settings.gpsBaud = 38400;
        settings.baudMagic = 42;
        ss=true;
      }
   }

   if((settings.messageMagic != 173) || (reset))
   {
    for(int i=0;i<10;i++)
     {
      strcpy(settings.TxMessage[i] , "EMPTY\r"); 
     } 
    settings.messageMagic = 173;
    ss=true; 
   }

  if((settings.locatorLength <6) || (settings.locatorLength > 10)|| (reset))
   {
    settings.locatorLength = 8;
    ss=true;
   }

  if((settings.decodeMode > 1)|| (reset))
   {
    settings.decodeMode =0;
    ss = true;
   }

  if((settings.txAdvance > 999)|| (reset))
   {
    settings.txAdvance =0;
    ss = true;
   }

  if((settings.rxRetard > 999)|| (reset))
   {
    settings.rxRetard =0;
    ss = true;
   }

  if((settings.batcal < 300) || (settings.batcal > 1000) || (reset))
   {
    settings.batcal = BATCAL;
   }

  if((settings.app >3)|| (reset)) 
   {
    settings.app = 0;
    ss = true;
   }

   if((settings.morseWpm > MORSE_MAX_WPM) || (settings.morseWpm < MORSE_MIN_WPM) || (reset))
   {
    settings.morseWpm = MORSE_DEFAULT_WPM;
    ss = true;
   }

   if(ss) saveSettings();
}

void saveSettings(void)
{
  EEPROM.put(0,settings);
  EEPROM.commit();
}

void clearEEPROM(void)
{
  for(int i=0;i<1024;i++)
   {
    EEPROM.write(i,0);
   }
   EEPROM.commit();
}


bool autoBaud(int rate)
{
  long baudTimer;
  char test[3];
  bool gotit;

  Serial2.begin(rate);                  //start GPS port comms
  baudTimer = millis();                    //make a note of the time
  gotit = false;
  while((millis() < baudTimer+2000) & (gotit == false))       //try 38400 for two seconds
    {
      if(Serial2.available())
       {
         test[0] = test[1];             //shift the previous chars up one
         test[1] = test[2];
         test[2]=Serial2.read();        //get the next char
         if((test[0] == 'R') & (test[1] == 'M') & (test[2] == 'C'))    //have we found the string 'RMC'?
          {
            gotit = true;
          }
       }
    }     
   Serial2.end();     
   return gotit;
}

//replaces a token with an expanded string. returns the result in new. 
void replaceToken(char * news, char * orig, char search, char * rep)
{
  if(rep[0] == '-')     //invalid Locator replaced by space for Morse code
   {
    rep[0] = ' ';
    rep[1] = 0;
   }
  int outp=0;
  for(int i=0 ; ;i++ )
    {
      if(orig[i] == search)
       {
         for(int q=0 ; ; q++)
          {
            if(rep[q] == 0)
             {
              break;
             }
            news[outp++] = rep[q];
          }
       }
      else 
       {
         news[outp++] = orig[i];
       }
       if(orig[i] == 0)
        {
          break;
        }
    }
}

bool checksum(const char *sentence) 
{
    if (sentence == NULL || sentence[0] != '$') 
    {
        return false;
    }

    const char *checksum_str = strchr(sentence, '*');
    if (checksum_str == NULL || strlen(checksum_str) < 3) 
    {
        return false;
    }

    unsigned char calculated_checksum = 0;
    for (const char *p = sentence + 1; p < checksum_str; ++p) 
    {
        calculated_checksum ^= (unsigned char)(*p);
    }

    unsigned int provided_checksum = 0;
    if (sscanf(checksum_str + 1, "%2x", &provided_checksum) != 1) 
    {
        return false;
    }

    return calculated_checksum == (unsigned char)provided_checksum;
}

//callback, called by FAT library whenever a file is created 
void dateTime(uint16_t* date, uint16_t* time) 
{

  // Set FAT date (bits: YYYYYYYMMMMDDDDD)
  *date = FAT_DATE(gpsYear + 2000, gpsMonth, gpsDay);

  // Set FAT time (bits: HHHHHMMMMMMSSSSS, seconds/2)
  *time = FAT_TIME(gpsHr, gpsMin, gpsSec);
}

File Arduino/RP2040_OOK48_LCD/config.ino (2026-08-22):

uint8_t ch;
TFT_eSPI_Button cfgKbd[CFG_NUMBEROFBUTTONS];

void configPage(void){
/*
Configuration items

6/8/10 character QTH locator
1S/2S Timing
GPS Baud Rate
Decode Mode
Tx Timing Advance
Rx Timing Retard
USB Download
*/

char txt[10];
bool done = false;
bool cfgLoop = false;
  while(!cfgLoop)
  {
  drawCFGKbd();
  delay(50); // UI debouncing
  showVoltage(true,0);
    while(!done)
    {

        // Pressed will be set true is there is a valid touch on the screen
        bool pressed = tft.getTouch(&t_x, &t_y);
        // / Check if any key coordinate boxes contain the touch coordinates
        for (uint8_t b = 0; b < CFG_NUMBEROFBUTTONS; b++) 
        {
          if (pressed && cfgKbd[b].contains(t_x, t_y)) 
          {
            cfgKbd[b].press(true);  // tell the button it is pressed
          }
          else 
          {
            cfgKbd[b].press(false);  // tell the button it is NOT pressed
          }
        }

        if(pressed && t_y > 300 && t_x > 200 && t_x <270)             //touch on voltage display 
         {
          txt[0] = 32;
           txt[1] = 0;
           getText("Enter Measured Voltage", txt,4);
           float entvolt = atof(txt);
           if((entvolt > 2.0)&(entvolt<6.0))
           {
           showVoltage(true,entvolt);                                    //recalibrate
           }
           done=true;
           ch=99;
         }

        // Check if any key has changed state
        for (uint8_t b = 0; b < CFG_NUMBEROFBUTTONS; b++) 
        {
          if (cfgKbd[b].justPressed()) 
          {
            ch=b;
            done = true;
          }
        }
       showVoltage(false,0);
    }

  switch(ch)
    {
    case 0:
      settings.locatorLength = 6;
      break;
    case 1:
      settings.locatorLength = 8;
      break;
    case 2:
      settings.locatorLength = 10;
      break;    
    case 3:
      if(settings.app == OOK48)
       {
        halfRate = false;
        cacheSize = CACHESIZE;
       }
      break;
    case 4:
      if(settings.app == OOK48)
       {
        halfRate = true;
        cacheSize = CACHESIZE *2;
       }
      break;
    case 5:
      settings.gpsBaud = 9600;
      settings.baudMagic = 42;
      Serial2.end();
      Serial2.begin(settings.gpsBaud);
      break;
    case 6:
      settings.gpsBaud = 38400;
      settings.baudMagic = 42;
      Serial2.end();
      Serial2.begin(settings.gpsBaud);
      break;
    case 7:
      GPSDebug = !GPSDebug;
      break;
    case 8:
      if(settings.app == OOK48)
       {
        settings.decodeMode = NORMALMODE;
       }
      break;
    
    case 9:
      if(settings.app == OOK48)
       {
        settings.decodeMode = ALTMODE;
       }
      break;
    case 10:
      if(settings.app == OOK48)
       {
        txt[0] = 32;
        txt[1] = 0;
        getText("Enter Tx Timing Advance in ms", txt,10);
        settings.txAdvance = atoi(txt);
        if(settings.txAdvance <0) settings.txAdvance = 0;
        if(settings.txAdvance >999) settings.txAdvance = 999;
       }
      if(settings.app == MORSE)
       {
        txt[0] = 32;
        txt[1] = 0;
        getText("Enter Default Morse Speed in WPM", txt,2);
        settings.morseWpm = atoi(txt);
        if(settings.morseWpm <MORSE_MIN_WPM) settings.morseWpm = MORSE_MIN_WPM;
        if(settings.morseWpm >MORSE_MAX_WPM) settings.morseWpm = MORSE_MAX_WPM;
       }
      break;
    case 11:
      if(settings.app == OOK48)
       {
        txt[0] = 32;
        txt[1] = 0;
        getText("Enter Rx Timing Retard in ms", txt,10);
        settings.rxRetard = atoi(txt);
        if(settings.rxRetard < 0) settings.rxRetard = 0;
        if(settings.rxRetard > 999) settings.rxRetard = 999;
       }
      break;
    case 12:
      if(sdpresent)
       {
         doUSBDrive();
       }
      break;
    case 13:
      cfgLoop = true;
      break;
    }
    done = false;
  }
}
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

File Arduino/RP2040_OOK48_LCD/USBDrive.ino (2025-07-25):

// create a USB Mass Storage device and link it to the SD Card
// Originated from Adafruit msc_sdfat example
// Must run undisturbed. LCD and touchscreen share the SPI Bus and cannot be used at the same time as the USB access to the SD card. 
//

void doUSBDrive(void)
{
  bool done = false;

  tft.fillScreen(TFT_BLACK);
  tft.setCursor(50,50);
  tft.setFreeFont(&FreeSansBold24pt7b);
  tft.setTextDatum(TL_DATUM);
  tft.setTextSize(1);
  tft.setTextColor(TFT_WHITE, TFT_BLACK);

  tft.println("USB Drive Mode");
  tft.setCursor(0,150);
  tft.println("Power off when done");
  tft.setCursor(0,250);
  tft.println("Connect to PC ------->");   
   

  initUSBDrive();
  while(!done)
   {
     // endless loop while USB transfers are in use. 
   }

}


void initUSBDrive(void)
{ 
  usb_msc.setID("OOK48", "SD Card", "1.0");       // Set disk vendor id, product id and revision with string up to 8, 16, 4 characters respectively 
  usb_msc.setReadWriteCallback(msc_read_cb, msc_write_cb, msc_flush_cb);      // Set read write callback
  usb_msc.setUnitReady(false);      // Still initialize MSC but tell usb stack that MSC is not ready to read/write
  usb_msc.begin();                  // If we don't initialize, board will be enumerated as CDC only

  if (TinyUSBDevice.mounted())      // If already enumerated, additional class driverr begin() e.g msc, hid, midi won't take effect until re-enumeration
  {
    TinyUSBDevice.detach();
    delay(10);
    TinyUSBDevice.attach();
  } 
 
  uint32_t block_count = sd.card()->sectorCount();     // Size in blocks (512 bytes)
  usb_msc.setCapacity(block_count, 512);              // Set disk size, SD block size is always 512
  usb_msc.setUnitReady(true);                         // MSC is ready for read/write
}

// Callback invoked when received READ10 command.
// Copy disk's data to buffer (up to bufsize) and
// return number of copied bytes (must be multiple of block size)
int32_t msc_read_cb (uint32_t lba, void* buffer, uint32_t bufsize) 
{
  bool rc;
  rc = sd.card()->readSectors(lba, (uint8_t*) buffer, bufsize/512);
  return rc ? bufsize : -1;
}

// Callback invoked when received WRITE10 command.
// Process data in buffer to disk's storage and 
// return number of written bytes (must be multiple of block size)
int32_t msc_write_cb (uint32_t lba, uint8_t* buffer, uint32_t bufsize) 
{
  bool rc;
  rc = sd.card()->writeSectors(lba, buffer, bufsize/512);
  return rc ? bufsize : -1;
}

// Callback invoked when WRITE10 command is completed (status received and accepted by host).
// used to flush any pending cache.
void msc_flush_cb (void) 
{
  sd.card()->syncDevice();
  sd.cacheClear();              // clear file system's cache to force refresh
}

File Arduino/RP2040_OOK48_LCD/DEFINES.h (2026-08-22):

#define VERSION "Version 0.36"

#define GPSTXPin 4                      //Serial data to GPS module 
#define GPSRXPin 5                      //Serial data from GPS module
#define TXPIN 6                         //Transmit output pin
#define KEYPIN 7                        //Key Output Pin
#define PPSINPUT 3                      //1 PPS signal from GPS 
#define ADC_CHAN 2                      //ADC2 is on GPIO Pin 28. Analogue input from Receiver. DC biased to half Supply rail.
#define ADC_VOLTS 3                     //ADC 3 is battery voltage/2
#define SDCLK 10                        //SD card Clock
#define SDI 11                          //SD card data in
#define SDO 12                          //SD card data out
#define SDCS 22                         //SD card select

#define REPEAT_CAL false              // Set REPEAT_CAL to true instead of false to run calibration again, otherwise it will only be done once.

#define SPECLEFT 0                    //Spectrum Display Left Edge in Pixels
#define SPECTOP 0                     //Spectrum Display Top Edge in Pixels
#define SPECWIDTH 204                 //Spectrum Width in Pixels 
#define SPECHEIGHT 100                //Spectrum Height in Pixels

#define LEGLEFT 0                     //Legend for spectrum display
#define LEGTOP 100
#define LEGWIDTH 204 
#define LEGHEIGHT 10

#define WATERLEFT 0                   //Waterfall Display Left Edge in Pixels
#define WATERTOP 110                  //Waterfall Display Top Edge in Pixels
#define WATERWIDTH 204                //Waterfall Disply Width in Pixels
#define WATERHEIGHT 165               //Waterfall Diaply Height in Pixels

#define TEXTLEFT 209                 //left edge of text output area
#define TEXTTOP 0                    //top edge of text output area
#define TEXTWIDTH 480-TEXTLEFT                //width of text output area
#define TEXTHEIGHT 275               //height of text output area

#define BUTSLEFT 0
#define BUTSTOP 280
#define BUTSWIDTH 480
#define BUTSHEIGHT 80

 
#define BUTWIDTH 70
#define BUTLEFT 5 + BUTWIDTH/2
#define BUTTOP 300
#define BUTHEIGHT 40
#define BUTGAP 10

#define BUTKEY_TEXTSIZE 1   // Font size multiplier

#define BUTLABEL_FONT &FreeSans9pt7b    // Button label font

// Setup/config selection start position, key sizes and spacing
#define CFG_X 0
#define CFG_WIDTH 480
#define CFG_HEIGHT 320
#define CFG_LINESPACING 20
#define CFG_TEXTLEFT 10
#define CFG_BUTTONSLEFT CFG_WIDTH/2
#define CFG_W 72 // Width and height
#define CFG_H 33
#define CFG_SPACING_X 10 // X and Y gap
#define CFG_SPACING_Y 20
#define CFG_TEXTSIZE 1   // Font size multiplier
#define CFG_NUMBEROFBUTTONS 14     //number of config buttons.

// OOK48 Spectrum display from 495Hz to 1098 Hz     Tone freq = 800 Hz
//Detection Values
#define OVERSAMPLE 8                                           //multiple samples are averaged to reduce noise floor. 
#define NUMBEROFSAMPLES 1024                                       // 1024 samples gives a scan rate of the bitrate
#define NUMBEROFOVERSAMPLES NUMBEROFSAMPLES * OVERSAMPLE              // ADC samples. will be averaged to number of Bins to reduce sampling noise.
#define SAMPLERATE 9216                                         //9216 samples per second with 1024 bins gives 9Hz sample rate and 9Hz bins. 
#define OVERSAMPLERATE SAMPLERATE * OVERSAMPLE         

#define BATCAL 587.0                                            //default battery calibration value. (can be reset in config menu)

#define STARTFREQ 495                                          //first frequency of interest (to nearest 9 Hz)
#define OOKSTARTBIN 55                                            // equivalent bin number from 512 FFT bins 
#define ENDFREQ 1098                                           //last frequency of interest (to nearest 9 Hz)

#define TONE800 34                                             // 800 Hz is the 34th bin between STARTFREQ and ENDFREQ

#define TONETOLERANCE 11                                        // 11 * 9  = 99Hz Tolerance

#define OOKNUMBEROFBINS 68                                         //68 bins between STARTFREQ and ENDFREQ

#define CACHESIZE 8                                           // 8 bits per character

//OOK48 Tx constants

#define TXINTERVAL 111111           //9 symbols per second in microseconds

#define LOCTOKEN 0x86


// Beacon Decoder Defines
//JT4G Detection Values
// Spectrum display from 498Hz to 1999 Hz  Tones 800 1115 1430 1745

#define JT4SAMPLERATE 4480              //4480 samples per second * oversample. FFT Bandwidth of 0-2240 Hz at 4.375 Hz
#define JT4OVERSAMPLERATE JT4SAMPLERATE * OVERSAMPLE
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

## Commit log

2025-06-09 Fix potential problem with 2 second mode.
    [RP2040_OOK48_LCD.ino, Rx.ino]
2025-06-12 Use TFT_ESPi Buttons on main page
2025-07-11 Add sample audio file
2025-08-07 Add 3D Enclosure files
    [OOK48 Box Lid.stl, OOK48 Box.stl]
2025-08-09 add 3d files
    [OOK48 Box Lid.stl, OOK48 Box.stl]
2025-08-09 Switch back to FFT
2025-08-10 Add battery voltage
2025-08-11 Add Battery Voltage calibration
2025-09-07 Update Enclosure
    [OOK48 Box.stl]
2026-03-01 Add NNew PCB Design
    [BOM.xls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]
2026-03-01 Revise README for hardware and enclosure information
    Updated hardware requirements and enclosure details for clarity.
2026-03-10 Revert "Morse"
    This reverts commit 86adffc41fab511197d9ef20eb1cfb0b509a1558.
    [GUI.ino, Rx.ino]
2026-03-12 Add WPM Display and buttons
2026-03-13 Change to fixed speed Morse decoding
    [DEFINES.h, GUI.ino, RP2040_OOK48_LCD.ino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]
2026-03-15 Fix bugs before release
    [GUI.ino, RP2040_OOK48_LCD.ino, Rx.ino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]
2026-03-16 Update 3D Enclosures
    [OOK48 Box Lid.stl, OOK48 Box.stl]
2026-03-17 Update new Box
    [OOK48 Box.stl]
2026-03-25 Reduce Touch pressure
    Some displays can't exceed 600 for Z pressure and so touches are not registered. Reduce this threshold to 300.
2026-03-26 Add Enclosure for typ B display
    [OOK48 Box A.stl, OOK48 Box B.stl, OOK48 Box Lid.stl]
2026-03-26 Clarify 3D printed enclosure and display variants
    Updated README to clarify 3D printed enclosure details and display variants.
2026-03-29 Update PCB
    [OOK48_PICO.kicad_pcb, OOK48_PICO.kicad_sch, OOK48_PICO_BOM.csv]
2026-04-29 Fix LOC keyboard entry and add GPS Debug MEssages
    [DEFINES.h, RP2040_OOK48_LCD.ino, TextPad.ino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]
2026-05-11 full settings clear on reset
    [DEFINES.h, GUI.ino, RP2040_OOK48_LCD.ino]
2026-05-14 corrrect error with morse '/'
    [DEFINES.h]
2026-07-24 Update Gerbers
2026-08-15 fix missing test on config page
    [DEFINES.h, config.ino]
2026-08-19 Revise README for HMI module connection and programming
    Updated instructions for connecting and programming the HMI module, clarified connections for Elecrow module and new PCB, and improved wording for clarity.
2026-08-22 improve battery voltage setting
2026-08-22 Revise voltage display calibration process
    Updated voltage display calibration instructions in README.
